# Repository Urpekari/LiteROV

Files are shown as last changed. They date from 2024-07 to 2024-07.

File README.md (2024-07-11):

# LiteROV

ROV arina hezkuntza erabilererarako. 3 motore, dual H-Bridge kontroladorea eta JoyC mandoaz erabiltzeko.

Light ROV system for educational purposes. 3 Motors, dual H-Bridge drive and JoyC Controls.

ROV ligero para fines educativos. Pensado para funcionar con 3 motores, controlador dual H-Bridge y mando JoyC.

## Authors

**Urpekari Proiektua - 2024**

EHU - Bilboko ingeniaritza eskola¡

University of the Basque Country - Bilbao school of engineering

UPV - Escuela de ingeinería de Bilbao

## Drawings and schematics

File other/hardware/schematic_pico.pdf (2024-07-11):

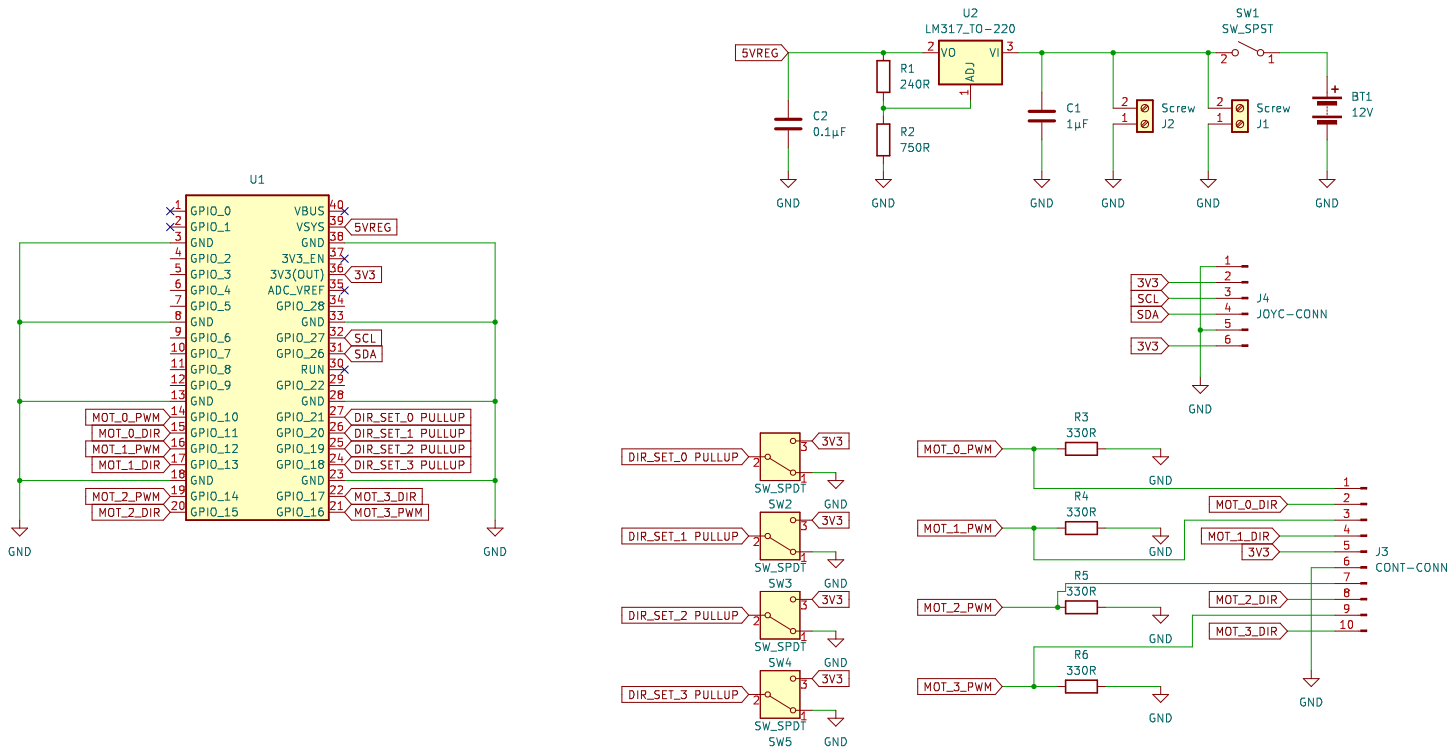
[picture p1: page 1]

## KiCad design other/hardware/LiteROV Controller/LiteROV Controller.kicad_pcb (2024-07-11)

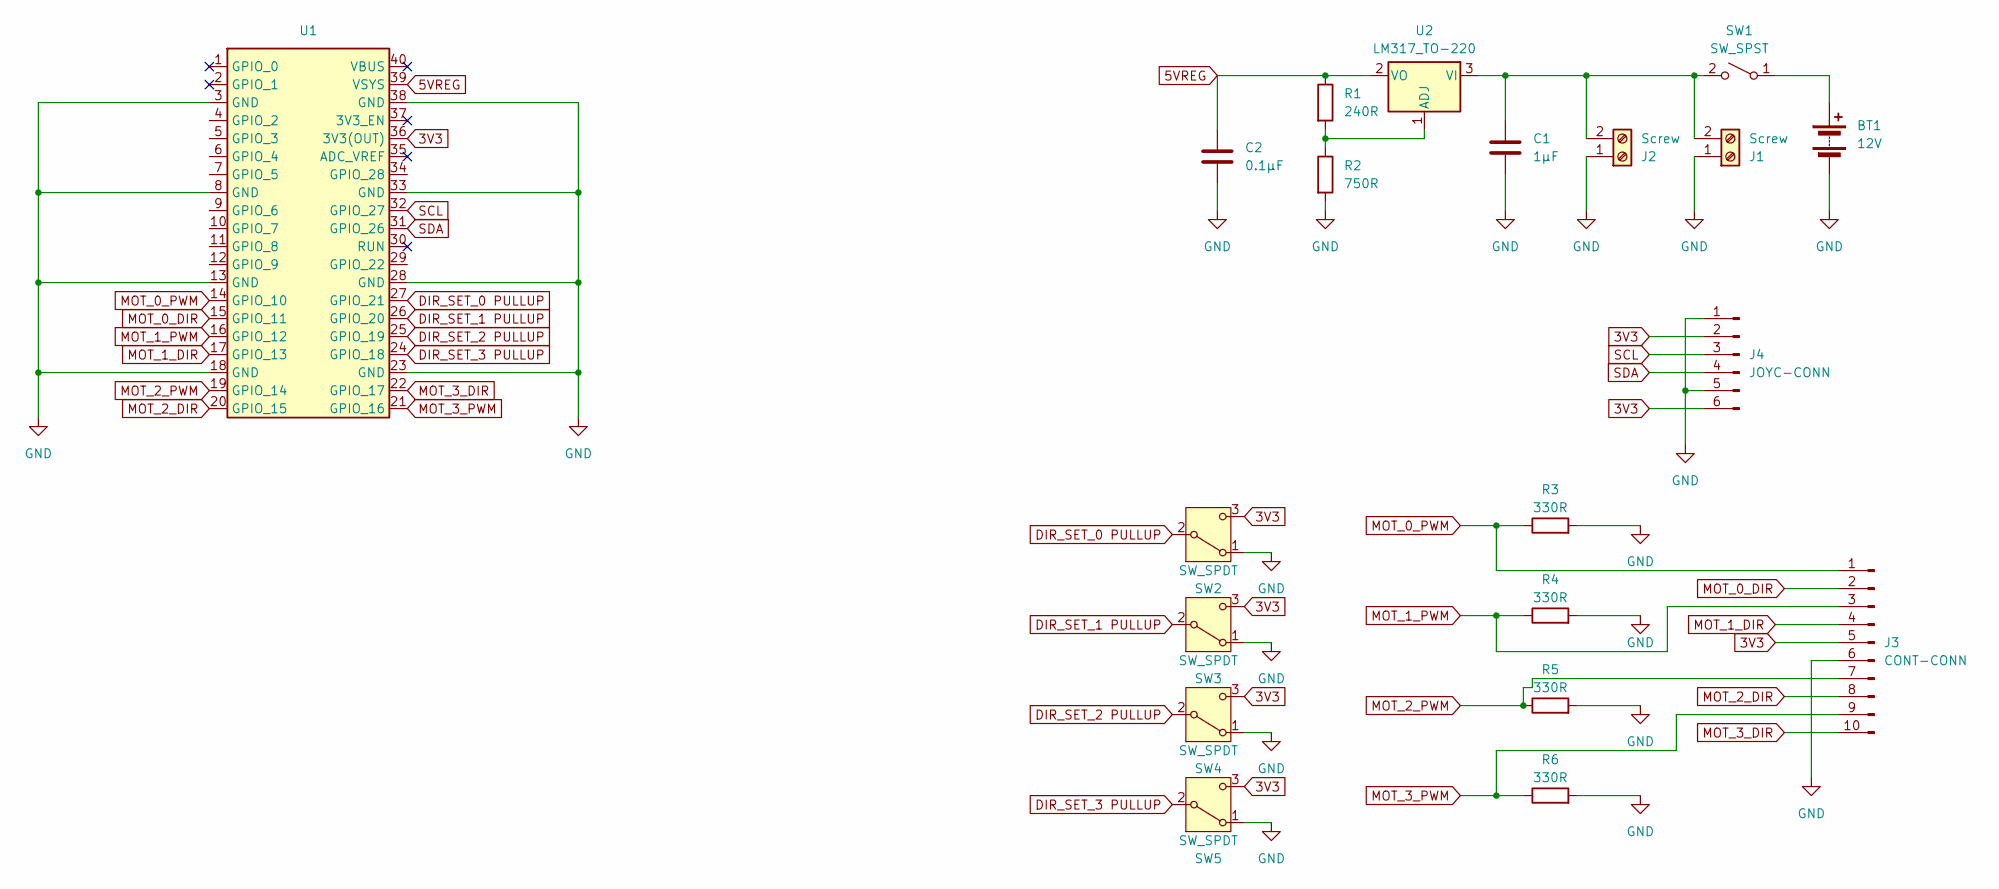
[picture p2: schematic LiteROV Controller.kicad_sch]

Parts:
BT1: 12V; BATTERY-CABLE
C1: 1µF; C_Rect_L9.0mm_W3.2mm_P7.50mm_MKT
C2: 0.1µF; C_Rect_L4.0mm_W2.5mm_P2.50mm
J1, J2: Screw; TerminalBlock_bornier-2_P5.08mm
J3: CONT-CONN
J4: JOYC-CONN
R1: 240R; R_Axial_DIN0207_L6.3mm_D2.5mm_P10.16mm_Horizontal
R2: 750R; R_Axial_DIN0207_L6.3mm_D2.5mm_P10.16mm_Horizontal
R3, R4, R5, R6: 330R; R_Axial_DIN0207_L6.3mm_D2.5mm_P10.16mm_Horizontal
SW1: SW_SPST; POWER-CABLE
SW2, SW3, SW4, SW5: SW_SPDT; SERVO
U1: RPI-PICO
U2: LM317_TO-220; TO-220-3_Vertical

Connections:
3V3: J3.5, J4.2, J4.6, SW2.3 (C), SW3.3 (C), SW4.3 (C), SW5.3 (C), U1.36 (3V3(OUT))
5VREG: C2.1, R1.1, U1.39 (VSYS), U2.2 (VO)
DIR_SET_0 PULLUP: SW2.2 (B), U1.27 (GPIO_21)
DIR_SET_1 PULLUP: SW3.2 (B), U1.26 (GPIO_20)
DIR_SET_2 PULLUP: SW4.2 (B), U1.25 (GPIO_19)
DIR_SET_3 PULLUP: SW5.2 (B), U1.24 (GPIO_18)
GND: BT1.2 (-), C1.2, C2.2, J1.1, J2.1, J3.6, J4.1, J4.5, R2.2, R3.2, R4.2, R5.2, R6.2, SW2.1 (A), SW3.1 (A), SW4.1 (A), SW5.1 (A), U1.3 (GND), U1.8 (GND), U1.13 (GND), U1.18 (GND), U1.23 (GND), U1.28 (GND), U1.33 (GND), U1.38 (GND)
MOT_0_DIR: J3.2, U1.15 (GPIO_11)
MOT_0_PWM: J3.1, R3.1, U1.14 (GPIO_10)
MOT_1_DIR: J3.4, U1.17 (GPIO_13)
MOT_1_PWM: J3.3, R4.1, U1.16 (GPIO_12)
MOT_2_DIR: J3.8, U1.20 (GPIO_15)
MOT_2_PWM: J3.7, R5.1, U1.19 (GPIO_14)
MOT_3_DIR: J3.10, U1.22 (GPIO_17)
MOT_3_PWM: J3.9, R6.1, U1.21 (GPIO_16)
unnamed: BT1.1 (+), SW1.1 (A)
unnamed: C1.1, J1.2, J2.2, SW1.2 (B), U2.3 (VI)
unnamed: R1.2, R2.1, U2.1 (ADJ)
SCL: J4.3, U1.32 (GPIO_27)
SDA: J4.4, U1.31 (GPIO_26)

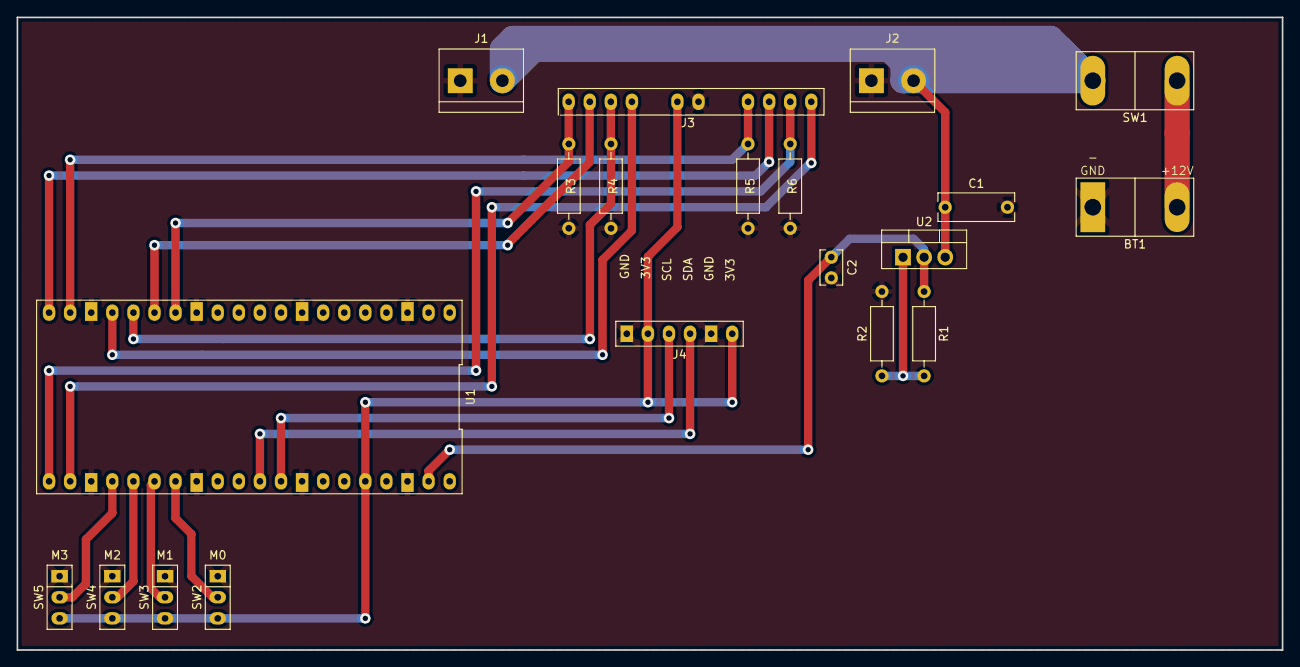
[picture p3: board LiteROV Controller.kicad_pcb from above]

Board: 2 copper layers, 152.4 x 76.2 mm, 20 parts (0 on the bottom side), 20 nets.

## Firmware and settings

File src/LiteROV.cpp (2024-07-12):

//v1.0
//2024-06-20

#include "pico/stdlib.h"
#include "JOYC.h"
#include "SERVO.h"

#define maxPWM 4096
#define MARGIN 25

uint8_t motorSpeed(int16_t speed, SERVO motor, uint8_t dirPin);
uint8_t steer(uint8_t xInput, uint8_t yInput, SERVO motL, SERVO motR, uint8_t dirL, uint8_t dirR);

int main(){
  
  stdio_init_all();
  
  struct outputs control;
  
  //NOTE: LOOK AT SERVO.cpp FOR AN EXPLANATION ON WHY THIS IS NECESSARY
  
  //These signals control the Enable (E) pins on the motor drivers
  SERVO mot0(10, 0, maxPWM);
  //We CAN'T use pull downs like this for output pins, for whatever reason they just don't work.
  //Add a physical Pull down resitor (At MOST 330 Ohm! I know, it's weird. I don't get it either!) to all the PWM channels
  //gpio_pull_down(10);
  SERVO mot1(12, 0, maxPWM);
  //We CAN'T use pull downs like this for output pins, for whatever reason they just don't work.
  //Add a physical Pull down resitor (At MOST 330 Ohm! I know, it's weird. I don't get it either!) to all the PWM channels
  //gpio_pull_down(12);
  SERVO mot2(14, 0, maxPWM);
  //We CAN'T use pull downs like this for output pins, for whatever reason they just don't work.
  //Add a physical Pull down resitor (At MOST 330 Ohm! I know, it's weird. I don't get it either!) to all the PWM channels
  //gpio_pull_down(14);
  
  //These signals control the Direction (M) pins on the motor drivers
  gpio_init(11);
  gpio_set_dir(11, GPIO_OUT);
  
  gpio_init(13);
  gpio_set_dir(13, GPIO_OUT);
  
  gpio_init(15);
  gpio_set_dir(15, GPIO_OUT);
  
  //Initialising the joystick driver
  JOYC joyc(1, 26, 27);
  
  while(1){
    control = joyc.getCartesian();
    
    //Normalising the values
    int8_t left0Norm = control.Left0-100;
    int8_t left1Norm = control.Left1-100;
    int8_t right0Norm = control.Right0-100;
    int8_t right1Norm = control.Right1-100;
    printf("Received: %4d %4d %4d %4d - %2d %2d\n", left0Norm, left1Norm, right0Norm, right1Norm, control.LButton, control.RButton);
    
    //I hate what I'm about to do.
    //Left0: 100 (Full Left)  -100 (Full Right)
    //Left1: 100 (Full Up)    -100 (Full Down)
    
    int8_t speedL;
    int8_t speedR;
    
    //Steer LEFT, speedR > speedL
    if(left0Norm < -MARGIN){
      speedL = left0Norm;
      speedR = -speedL;
      printf("LEFT!!\n");
    }
    else if(left0Norm > MARGIN){
      speedL = left0Norm;
      speedR = -speedL;
      printf("RIGHT!!\n");
    }
    else{
      printf("FORWARDS!! (Or backwards idk)\n");
      speedL = left1Norm;
      speedR = left1Norm;
    }
    
    motorSpeed(speedL, mot0, 11);
    motorSpeed(speedR, mot1, 13);
    
    //We can run the Z motor directly off of the Y axis on the right Joystick
    motorSpeed(right1Norm, mot2, 15);
  }
  
  return(0);
}


//This takes a normalised speed (S€[-100, 100]) value
uint8_t motorSpeed(int16_t speed, SERVO motor, uint8_t dirPin){
    
    //printf("Received speed: %d\n", speed);
    
    if(speed > MARGIN*2){
      motor.moveServo(speed);
      gpio_put(dirPin, 0);
      return(speed);
    }
    else if(speed < 0-(MARGIN*2)){
      motor.moveServo(-speed);
      gpio_put(dirPin, 1);
      return(-speed);
    }
    else{
      motor.moveServo(0);
      gpio_put(dirPin, 0);
      return(0);
    }
}

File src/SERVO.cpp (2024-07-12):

//v1.0
//2024-06-07

/*
  LITEROV NOTE:
  To whoever reads this: I did not want to figure out PWM on the Raspberry Pi Pico again.
  So instead of doing that, I used the Servo Control library I made for my own personal projects.
  I plan on getting rid of this some day... but in the meantime: I modified it to have a larger duty cycle dynamic range.
  If you want to implement the same thing as this in arduino, don't: analogWrite() is what you want. It does exactly what we want.
  The raspberry pi pico has no easy PWM setup that I can find. Maybe the defaults are what I want? Either way, this works!
  
  LITEROV NOTA:
  A quien pueda interesar: No quería volver a adivinar como funciona el PWM en la Raspberry Pi Pico otra vez.
  En lugar de hacer eso, usé la librería de control de servos que hice para proyectos personales.
  Pretendo librarme de esto algun día, pero hasta entonces: He modificado esta para que use mas duty cycle.
  Si quieres implementar algo como esto pero en arduino, no lo hagas: analogWrite() es lo que buscas. Hace exactamente lo que esto intenta hacer.
  No sé si la raspberry Pi Pico tiene un setup default util o no, pero esto funciona.
  
  LITEROV OHARRA:
  Irakurtzen duenari: Ez nuen Raspberry Pi Pico-ren PWM-ak zelan funtzionatzen zuten berriz asmatu nahi.
  Horren ordez, nire proiektu pertsonaletarako erabili nuen servo kontrol liburutegia erabili dut.
  Hau kentzea dut planeatuta noizbati... baina bitartean: Duty Cycle-a hobeto erabiltzeko modifikatu dut.
  Honelako zeozer inplementatu nahian arduinon, ez egin: analogWrite() da nahi duzuna. Honek egin nahi duena egiten du zuzenean.
  Ez dakit Raspberry Pi Pico-ak default erabilgarririk duen ala ez, baina beharbada, hau funtzionatzen du.
  
*/

#include <SERVO.h>
#include "pico/stdlib.h"
#include "stdio.h"
#include "hardware/pwm.h"
#include "hardware/clocks.h"
#include "pico/time.h"
#include "hardware/irq.h"

SERVO::SERVO(uint8_t pin)
{
    this -> pin = pin;
    this -> min = 200;
    this -> max = 1200;

    config();
}

SERVO::SERVO(uint8_t pin, uint16_t min, uint16_t max)
{    
    this -> pin = pin;
    this -> min = min;
    this -> max = max;

    config();
}

void SERVO::config(){
    gpio_init(this -> pin);
    gpio_set_function(pin,  GPIO_FUNC_PWM);

    this-> slice = pwm_gpio_to_slice_num(this -> pin);
    this-> channel = pwm_gpio_to_channel(this -> pin);

    pwm_set_clkdiv(slice, 256.0f);
    pwm_set_wrap(slice, 9804);
    pwm_set_enabled(slice, true);
}

//Literally the map function in arduino
uint16_t SERVO::convertAngle(uint8_t receivedPos, uint16_t min, uint16_t max){

    //receivedPos   : The input value we want to convert
    //in_min        : Lower limit of all possible inputs
    //in_max        : Upper limit of all possible inputs
    //this->min       : Lower limit of the desired outputs
    //this->max       : Upper limit of the desired outputs

    
      //Case-specific modification: DO NOT MERGE INTO REGULAR LIBRARY!
      uint8_t in_min = 0;
      uint8_t in_max = 95;

    return( (receivedPos - in_min) * (max - min) / (in_max - in_min) + min);
}

SERVO::~SERVO(){
}

void SERVO::moveServo(uint8_t pos){
    uint16_t correctedVal = convertAngle(pos, (this->min), (this->max));
    //printf("Servo pos: %d \n", correctedVal);
    pwm_set_chan_level(this->slice, this->channel, correctedVal);
}

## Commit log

2024-06-19 Basic single-motor functions implemented
2024-06-20 LiteROV v1.0
    The basic functions are there, it may require a bit of polishing but it should work.
    It will be tested with the actual motors on 2024-06-21
2024-07-11 Added schematics, PCB design
    [LiteROV Controller.kicad_pcb, LiteROV Controller.kicad_sch]
2024-07-12 directory cleanup
    [LiteROV Controller.kicad_pcb, LiteROV Controller.kicad_sch]
2024-07-12 Clearup notes
    Notes added regarding the usage of the SERVO library and its modifications.
